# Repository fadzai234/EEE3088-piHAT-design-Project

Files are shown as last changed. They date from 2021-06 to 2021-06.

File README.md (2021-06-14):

# EEE3088-piHAT-design-Project
The objective of this project is to design a raspberry piHAT which can sense and log temperatures in environments such as refrigerators and geysers.

The piHAT will be attached to the raspberry pi zero which wil be used to record the temperature measurements which are recieved from a pre-designed temperature sensor board.

The sense microHat will sense and monitor temperature readings. The Hat will be attached to a predesigned sensor that will measure the temperature as a function of voltage and this will be converted to degrees using an analogue to digital convertor. This microHat can be used in a home weather station to measure environmental temperature, in electronic devices or in home automation systems such as a geyser.

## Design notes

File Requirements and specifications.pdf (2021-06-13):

# Requirements and specifications for a temperature sensing piHAT

The aim of this report is to outline the requirements and specs of a piHAT which senses temperature to be designed.

# Requirements for possible Use cases

## Home Weather Station

R1.1: Measure temperature accurately to 0.5 °C.
R1.2: Notify user once temperature exceeds a certain voltage.
R1.3: Device should be capable of operating for long continuous periods of time. R1.4 Should be able to work with any standard Pi.
R1.5 Notify user of the temperature operating range.

## Soil Temperature Monitor

R2.1: Should not be too sensitive to temperatures within a certain range.
R2.2: Should be water resistant.
R2.3: Should not read external temperature accidentally.
R2.4: The device should notify the user when soil temperatures near the end of the acceptable range.

## Geyser Temperature Display

R3.1: Should be able to function properly and accurately even when exposed to temperatures up to 60°C.
R3.2: Should be small and weigh less enough for it to not be a burden on the geyser and affect its functions.
R3.3: Should notify the user when it reaches 60°C.
R3.4: The device should require minimal power to operate fully.

## Refrigerator unit temperature logging

R4.1: The piHAT should log the temperature of the refrigerator at regular intervals R4.2: Device should not be affected by humidity.
R4.3: The device should be on while the refrigerator is on.

# Q3 Specifications [20]

## Mechanical Specifications

Requirement | Specification(s) | Acceptance Test Criteria
R1.4 Should be able to work with any standard Pi | S1.1 should include 40pin Pi compliant header S1.2 Should have at least an 8mm gap betweeen the piHAT and raspberry pi. This can be achieved with 10 mm spacers. | Final design meets the specification
R3.2 Should be small in dimensions | S1.3 Should have 76.0mm x 40.5mm x 7.0mm | Final design dimensions are within limits

## Electrical Specification

Requirement | Specification(s) | Acceptance Test Criteria
R 1.4 Should be able to work with any standard Pi. | S1.4 Have an operating voltage of 0-3.3V S1.4 The power supply should step voltage down from 230V. | Have a power supply that is limited to 3.3V
R 3.1 Should be able to measure low temperatures e.g soil temperature and higher ones (e.g for a geyser) | S1.5 Temperature sensor should have -50°C - 250°C temperature range | The final design will be chamber tested at -50°C and 60°C for 12 hours, the components used in the design should also be able to operate under these

| | conditions/ have a specific temperature coefficients.
R1.1: Measure temperature accurately to 0.5 °C | S1.6 use a 9 bit resolution temperature sensor eg PT100 | Use an external thermometer to verify if results are accurate.
R1.3: Device should be capable of operating for long continuous periods of time | S1.7 have a constant uninterrupted power supply attached to the HAT | Design meets the specification

## Functional Specifications

Requirement | Specification(s) | Acceptance Test Criteria
R1.2: Notify user once temperature exceeds a certain voltage. | S1.8 Blue LED should light up once a temperature of 60°C has been reached. | Design meets the specification.
R1.5 Notify user of the temperature operating range. | S1.9 Red LED for 0-2V (0-30°C) Green LED for 2-3.2 V( 30 -59°C) Blue LED for 3.3V (60°C) | Final design is tested for temperatures within each range for each LED. Repeat tests must be done and the piHAT must pass all tests.
R2.2 Should be water-resistant | S1.10 The outer covering of the sensor should be sealed with a water resistant eg silicone. | Should pass IP53 testing

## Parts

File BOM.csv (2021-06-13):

Source: | C:\Users\Fadzai\Desktop\Academic 2021\eee3088\Proj1\3088\3088.sch
Date: | 2021/06/13 10:51:07
Tool: | Eeschema (5.1.10)-1
Generator: | C:\Program Files\KiCad\bin\scripting\plugins/bom_csv_grouped_by_value_with_fp.py
Component Count: | 31
Ref | Qnty | Value | Cmp name | Footprint | Description | Vendor
C1, | 1 | 1u | C | Capacitor_SMD:CP_Elec_4x3 | Capacitor symbol for simulation only
C2, C5, | 2 | 10n | C | Capacitor_SMD:CP_Elec_4x3 | Capacitor symbol for simulation only
C3, | 1 | 0.047u | C | Capacitor_SMD:CP_Elec_4x3 | Capacitor symbol for simulation only
C4, | 1 | 2.2u | C | Capacitor_SMD:CP_Elec_4x3 | Capacitor symbol for simulation only
D1, | 1 | LED_BCGR | LED_BCGR | LED_SMD:LED_0201_0603Metric | RGB LED, blue/cathode/green/red
D2, | 1 | LED | LED | LED_SMD:LED-L1T2_LUMILEDS | Light emitting diode
H1, H2, H3, H4, | 4 | MountingHole | MountingHole | lib:MountingHole_2.7mm_M2.5_uHAT_RPi | Mounting Hole without connection
IC1, | 1 | LT8618EDDB-3.3#TRPBF | LT8618EDDB-3.3#TRPBF | LT8618EDDB-3.3#TRPBF:SON50P200X300X80-11N-D | Switching Voltage Regulators High Efficiency 60V/100mA Synchronous Bu
J1, | 1 | GPIO_CONNECTOR | Conn_02x20_Odd_Even | lib:PinSocket_2x20_P2.54mm_Vertical_Centered_Anchor | Generic connector, double row, 02x20, odd/even pin numbering scheme (row 1 odd numbers, row 2 even numbers), script generated (kicad-library-utils/schlib/autogen/connector/)
J2, | 1 | Screw_Terminal_01x01 | Screw_Terminal_01x01 | TerminalBlock:TerminalBlock_Altech_AK300-2_P5.00mm | Generic screw terminal, single row, 01x01, script generated (kicad-library-utils/schlib/autogen/connector/)
L1, | 1 | 120u | INDUCTOR | TerminalBlock:TerminalBlock_Altech_AK300-2_P5.00mm | Inductor symbol for simulation only
Q1, | 1 | AO3401A | AO3401A | Package_TO_SOT_SMD:SOT-23 | -4.0A Id, -30V Vds, P-Channel MOSFET, SOT-23
Q2, | 1 | 2N2219 | 2N2219 | Package_TO_SOT_THT:TO-39-3 | 800mA Ic, 50V Vce, NPN Transistor, TO-39
R1, | 1 | 4700 | R | Resistor_SMD:R_0201_0603Metric_Pad0.64x0.40mm_HandSolder | Resistor
R2, | 1 | 110k | R_Small | Resistor_SMD:R_0201_0603Metric_Pad0.64x0.40mm_HandSolder | Resistor, small symbol
R3, | 1 | 5000 | R | Resistor_SMD:R_0201_0603Metric_Pad0.64x0.40mm_HandSolder | Resistor
R4, | 1 | 47000 | R | Resistor_SMD:R_0201_0603Metric_Pad0.64x0.40mm_HandSolder | Resistor
R5, | 1 | 100k | R_Small | Resistor_SMD:R_0201_0603Metric_Pad0.64x0.40mm_HandSolder | Resistor, small symbol
R6, | 1 | 47.5 | R | Resistor_SMD:R_0201_0603Metric_Pad0.64x0.40mm_HandSolder | Resistor
R7, | 1 | 40 | R | Resistor_SMD:R_0201_0603Metric_Pad0.64x0.40mm_HandSolder | Resistor
R8, | 1 | 12.5 | R | Resistor_SMD:R_0201_0603Metric_Pad0.64x0.40mm_HandSolder | Resistor
R9, | 1 | 330 | R_Small | Resistor_SMD:R_0201_0603Metric_Pad0.64x0.40mm_HandSolder | Resistor, small symbol
R10, | 1 | 5000 | R_Small | Resistor_SMD:R_0603_1608Metric | Resistor, small symbol
TempSensor1, | 1 | PT100 | PT100 | Resistor_SMD:R_0805_2012Metric | PT100 platinum temperature sensor (RTD)
U2, | 1 | LM741 | LM741 | Package_SO:SOIC-8-1EP_3.9x4.9mm_P1.27mm_EP2.29x3mm | Operational Amplifier, DIP-8/TO-99-8
U3, | 1 | ADC081C021CIMM | ADC081C021CIMM | Package_SO:MSOP-8_3x3mm_P0.65mm | I2C-Compatible, 8-Bit Analog-to-Digital Converter with Alert Function, MSOP-8
ZVD1, | 1 | DIODE | DIODE | Diode_SMD:D_0201_0603Metric | Diode symbol for simulation only. Pin order incompatible with official kicad footprints

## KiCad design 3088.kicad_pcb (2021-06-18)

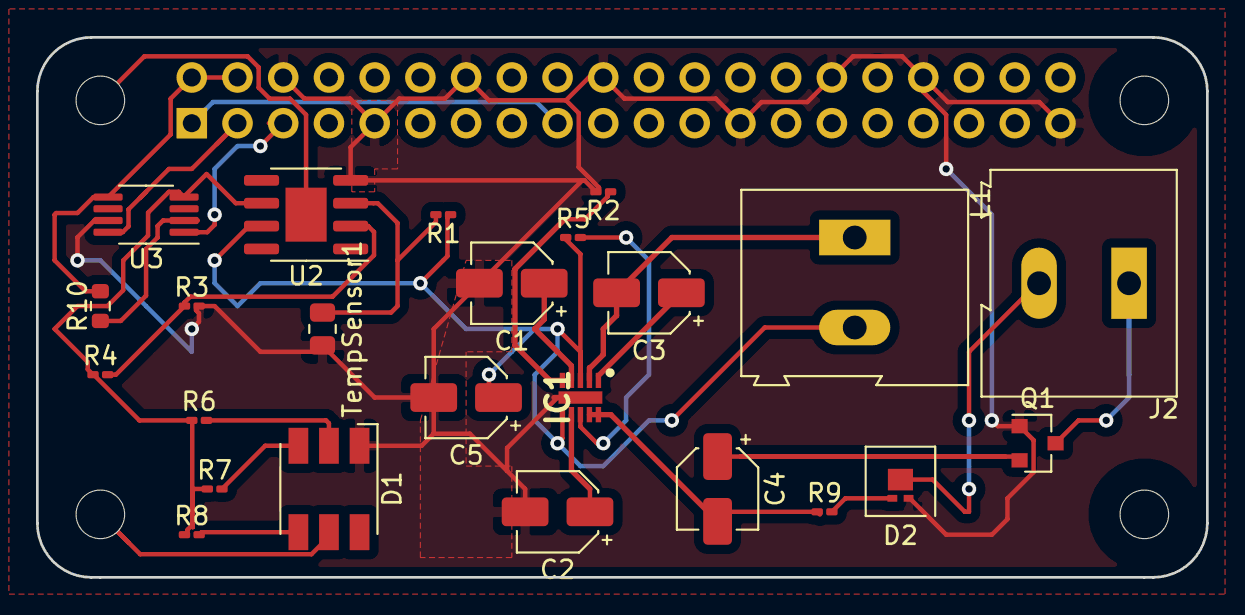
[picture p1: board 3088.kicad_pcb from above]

Board: 2 copper layers, 65.0 x 30.0 mm, 29 parts (1 on the bottom side), 23 nets.

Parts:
C1: 1u; CP_Elec_4x3
C2, C5: 10n; CP_Elec_4x3
C3: 0.047u; CP_Elec_4x3
C4: 2.2u; CP_Elec_4x3
D1: LED_ABGR; LED_RGB_5050-6
D2: LED; LED-L1T2_LUMILEDS
H1, H2, H3, H4: MountingHole; MountingHole_2.7mm_M2.5_uHAT_RPi
IC1: LT8618EDDB-3.3#TRPBF; SON50P200X300X80-11N-D
J1: GPIO_CONNECTOR; PinSocket_2x20_P2.54mm_Vertical_Centered_Anchor
J2: Screw_Terminal_01x01; TerminalBlock_Altech_AK300-2_P5.00mm
L1: 120u; TerminalBlock_Altech_AK300-2_P5.00mm
Q1: AO3401A; SOT-23
R1: 4700; R_0201_0603Metric_Pad0.64x0.40mm_HandSolder
R2: 110k; R_0201_0603Metric_Pad0.64x0.40mm_HandSolder
R3: 5000; R_0201_0603Metric_Pad0.64x0.40mm_HandSolder
R4: 47000; R_0201_0603Metric_Pad0.64x0.40mm_HandSolder
R5: 100k; R_0201_0603Metric_Pad0.64x0.40mm_HandSolder
R6: 47.5; R_0201_0603Metric_Pad0.64x0.40mm_HandSolder
R7: 40; R_0201_0603Metric_Pad0.64x0.40mm_HandSolder
R8: 12.5; R_0201_0603Metric_Pad0.64x0.40mm_HandSolder
R9: 100; R_0201_0603Metric_Pad0.64x0.40mm_HandSolder
R10: 5000; R_0603_1608Metric
TempSensor1: PT100; R_0805_2012Metric
U2: LM741; SOIC-8-1EP_3.9x4.9mm_P1.27mm_EP2.29x3mm
U3: ADC081C021CIMM; MSOP-8_3x3mm_P0.65mm

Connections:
+3V3: J1.1, J1.17
+5V: J1.2, J1.4, R10.2, U3.5
+12V: J2.1, Q1.3
GND: C1.2, C2.2, C5.2, D1.1, D2.1, IC1.11, J1.6, J1.9, J1.14, J1.20, J1.25, J1.30, J1.34, J1.39, Q1.1, R2.2, R3.2, TempSensor1.2, U2.4, U3.7
unnamed: C4.1, Q1.2
unnamed: D1.2, R6.2
unnamed: D1.3, R7.2
unnamed: D1.4, R8.2
unnamed: D2.2, R9.2
unnamed: R1.2, TempSensor1.1, U2.3
unnamed: R3.1, R4.2, U2.2
unnamed: R10.1, U3.2
OUT: C5.1, IC1.3, IC1.6, L1.2, R1.1, R5.1, U2.7
SCL: J1.5, U3.1
SDA: J1.3, U3.8
VopAmpOut: R4.1, R6.1, R7.1, R8.1, U2.6, U3.4
Vreg_BST: C3.1, IC1.1
Vreg_ENUV: C4.2, IC1.9, IC1.10, R9.1
Vreg_INTVCC: C1.1, IC1.4
Vreg_PG: IC1.8, R5.2
Vreg_RT: IC1.5, R2.1
Vreg_SW: C3.2, IC1.2, L1.1
Vreg_TRSS: C2.1, IC1.7

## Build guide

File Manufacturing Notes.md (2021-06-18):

1. The PCB material should allow the PiHat to function in the temperature range of 0-70 degrees celcious.
2. The PCB material should be water resistant
3. The PCB material should be light enough not to exceed 500grams
3. The PCB material should be durable. It should be able to last at least 18 months working.

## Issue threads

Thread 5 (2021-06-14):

Op Amp Circuit Issues

TheDarkLvrd, 2021-06-14:
The circuit works but its still not outputting within the 0-3V3 voltage range. The problem lies with the choice of Op Amp and resistor values choice.

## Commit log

2021-06-04 Added the project kicad files for version 2
2021-06-04 final pcb files for the pi hat project
2021-06-04 Added the LT8618 part for KICAD
    The symbol and footprints are included.
2021-06-11 how the LEDs work
2021-06-13 Bill of Materials
    [BOM.csv]
2021-06-14 Create How the LEDs work
2021-06-18 Added PCB v2
    This version of the pcb hs 2 layers instead of 4 which is more approprate for this system.
    [3088.kicad_pcb]
2021-06-18 Added the other files necessary forthe pcb

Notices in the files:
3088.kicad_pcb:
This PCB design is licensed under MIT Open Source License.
